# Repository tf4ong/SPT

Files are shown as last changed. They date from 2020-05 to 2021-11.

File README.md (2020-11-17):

# Home-cage Sucrose Preference Test
A scipt to run a chronic automated sucrose preference test of mice in home cage. The script is ran on a raspberry-pi with internet connection. A sucrose preference tunnel is attached to a rodent cage. The tunnel consists of a RFID reader for mouse identification, two double spouts for liquid dispension, capacitive touch sensor for lick detection, selenoids for reward delivery, IR light, and a fish-lens camera for behavior monitoring. An updated hardware list and setup instructions will be uploaded shortly. 
## MySql Database for Data Storage
- All behaviroal data (entries, exits, spout licked, type of reward dispensed) are logged on to the raspberry-pi MySql database. 
- The database is also hosted  by Apache HTTP Sever(version 2.4.43) and can be accessed through the internet
- Subsequent analytical scripts will also be uploaded
## RFID Identification
- A ID-20LA RFID tag reader will be at the beginning of the SPT tunnel to identify each mouse
## Spout choice At the of the Sucrose Preference Test Tunnel
- At the end of the tunnel there are two double spouts on each side
- The mouse and the spouts are spearted by a customed cut acrylic plastic (one hole corresponds to one double spout)
- A reward water/sucrose water is dispensed for every n links at each double spout. The n number of licks can be set accordingly
- Every 24 hour, the side which dispenses water/sucrose is swaped for the specific mouse
### Design and Layout of the Sucrose Preference Tunnel
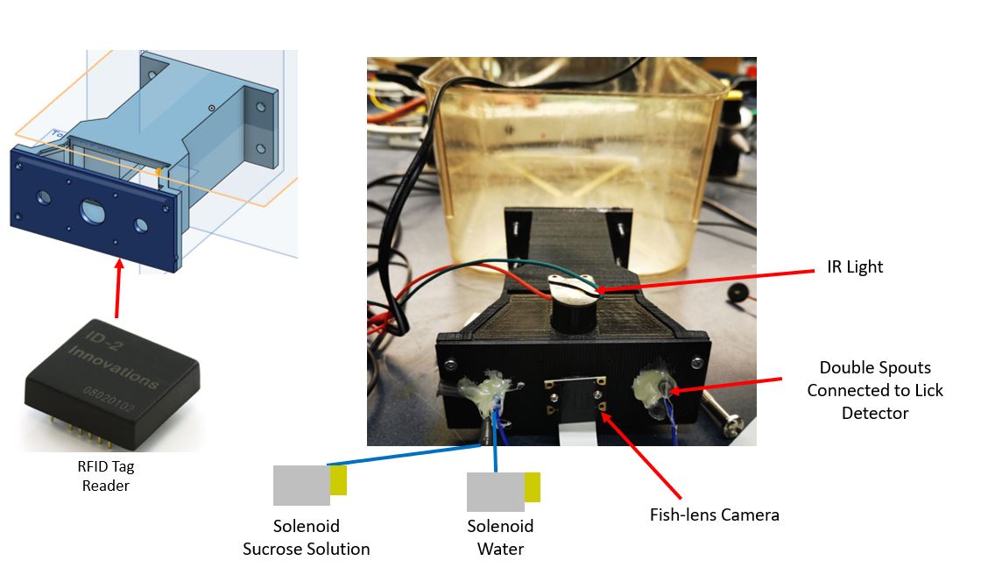
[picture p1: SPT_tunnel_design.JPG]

#### CAD Parts Assembly 
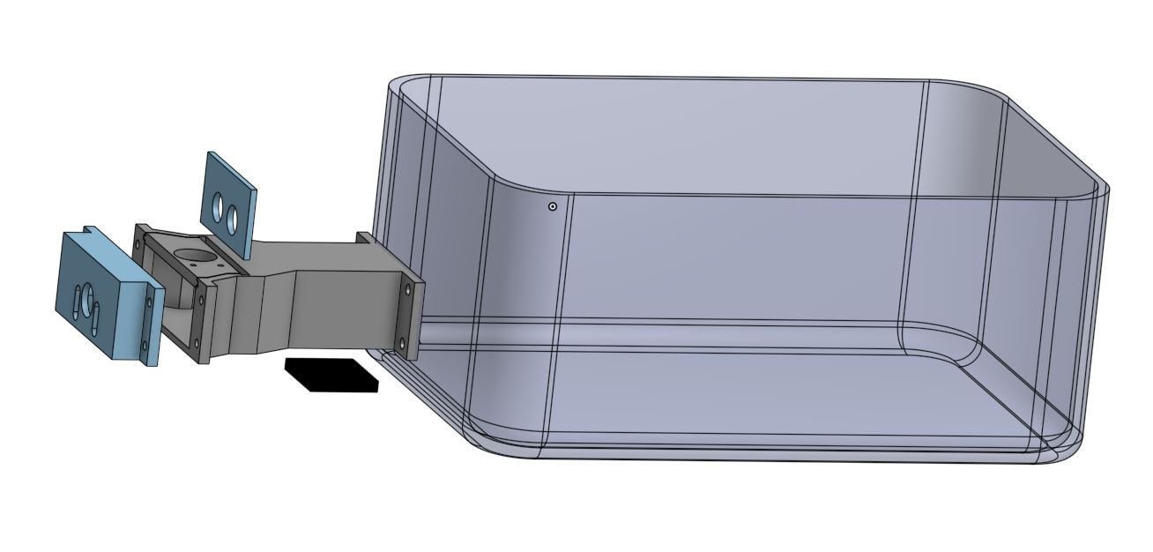
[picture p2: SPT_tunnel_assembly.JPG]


## Some Preliminary Videos
### Mouse Licking Spouts For Rewards In The Sucrose Preference Test Tunnel
Mouse Licking Right Spout             |  Mouse Licking Left Spout
:-------------------------:|:-------------------------:
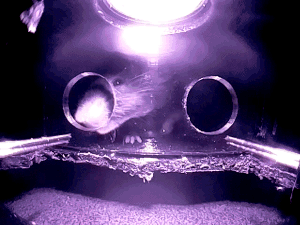
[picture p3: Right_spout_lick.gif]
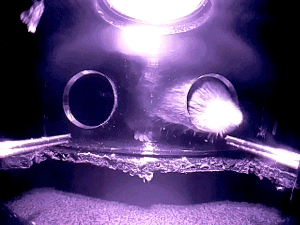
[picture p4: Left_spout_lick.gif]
 |

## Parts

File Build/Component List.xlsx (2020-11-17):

Component | Location | Price | Currency | Total Price in CAD | Notes | appendex | appendex | appendex
Raspberry Pi 3B + SD+power supply | https://www.buyapi.ca/product/raspberry-pi-3-model-b-plus/?src=raspberrypi | $67.85 | CAD | $67.85
Pi Cobbler | https://www.adafruit.com/product/2029 | $6.95 | USD | $8.69
Perma-Proto Board | https://www.adafruit.com/product/1606 | $6.95 | USD | $8.69
Bipolar (BJT) Transistor NPN | https://www.digikey.ca/en/products/detail/on-semiconductor/BC547BTA/1532789 | $0.30 | CAD | $1.20 | Four needed per cage
Solenoid Valve | http://canada.newark.com/gems-sensors/mb202-vb30-l203/solenoid-valve/dp/45M6131 | $99.47 | CAD | $397.88 | Four needed per cage; possible alternative (listed in appendex), price can be reduced from 397.88 to 95.94 ( including tubings) | https://www.amazon.ca/Pneumatic-Connector-Fittings-Industry-Automatic/dp/B07BLRG8SH | https://www.amazon.ca/URBEST-Meter-39-4ft-Pneumatic-Fittings/dp/B01M0DM5X5 | https://www.amazon.com/Normally-Pneumatic-Aluminum-Electric-Solenoid/dp/B07J4P99YZ
RFID USB Reader | https://www.sparkfun.com/products/9963 | $26.50 | USD | $33.12
RFID Reader ID20-LA | https://www.sparkfun.com/products/11828 | $34.95 | USD | $43.69
RFID Glass Capsules | https://www.sparkfun.com/products/9416 | $4.95 | USD | $6.19 | One is needed per animal to be tested (can be reused)
Mini-USB Cable | https://www.amazon.ca/AmazonBasics-USB-2-0-Cable-Male/dp/B00NH11N5A | $10.71 | CAD | $10.71
RPi Camera (G) | https://www.waveshare.com/product/rpi-camera-g.htm | $24.99 | USD | $31.24
18" Flex Cable | https://www.adafruit.com/product/1730 | $1.95 | USD | $2.44
TVS Diode | http://canada.newark.com/fairchild-semiconductor/p6ke36a/tvs-diode-600w-36v-do-15/dp/58K2101 | $0.22 | CAD | $0.88 | Four needed per cage
4.7kOhm Resistor | http://canada.newark.com/multicomp/mcre000041/carbon-film-resistor-axial-lead/dp/24R6895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 | $0.12 | CAD | $0.12
12V 1A Power Supply | https://www.adafruit.com/product/798 | $8.95 | USD | $11.19 | If building multiple cages, I recommend instead buying a 12V 5A charger, a four way splitter cable and extension cables (all available on adafruit)
Female DC Power to Screw Terminal | https://www.adafruit.com/product/368 | $2.00 | USD | $2.50
In-line Power Switch | https://www.adafruit.com/product/1125 | $2.50 | USD | $3.12
32 Oz Bottle w/Tubulation | https://www.usplastic.com/catalog/item.aspx?sku=68024&catid=1148 | $26.84 | USD | $67.10 | two bottles needed
1/8" Beverage Tubing | https://www.usplastic.com/catalog/item.aspx?sku=54413&catid=1065 | $5.83 | USD | $7.29 | Price is for a 25' roll (much less required for one cage)
1/4" Beverage Tubing | https://www.usplastic.com/catalog/item.aspx?itemid=85094 | $23.65 | USD | $29.56 | Price is for a 25' roll (much less required for one cage)
1/4" to 1/8" Coupler | https://www.usplastic.com/catalog/item.aspx?itemid=42622 | $0.59 | USD | $0.74
1/8" Luer | https://www.usplastic.com/catalog/item.aspx?itemid=118337 | $33.28 | USD | $41.60 | Price is for a pack of 100, but only two needed per system. Can be purchased in smaller packages on other websites (e.g. Sigma Aldrich).
3/16" Tubing Clamp | https://www.usplastic.com/catalog/item.aspx?sku=16004&catid=858 | $3.99 | USD | $4.99
18G Needle | https://www.mywellcare.ca/index.php?route=product/product&path=5&product_id=2778 | $22.00 | CAD | $22.00
3mm Acrylic Nose Poke Port |  | ???
Total Price: | $802.78

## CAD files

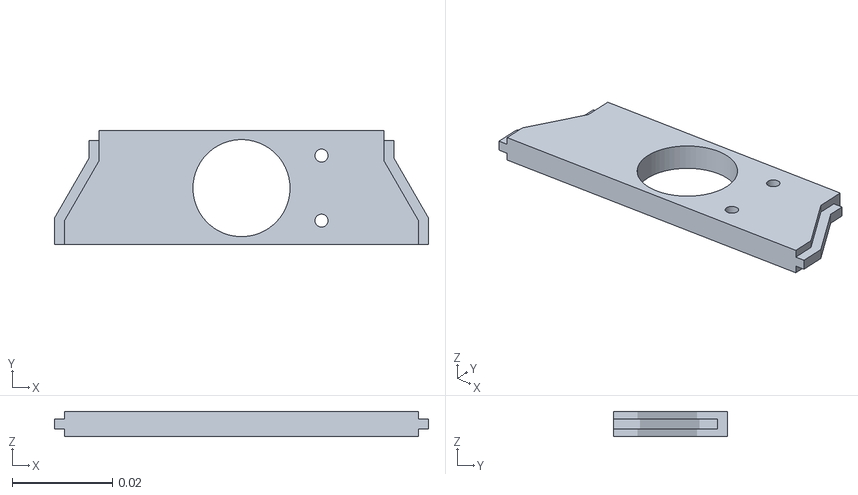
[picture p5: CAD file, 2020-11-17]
Build/CAD files/SPT chamber top.stl
0.0748 x 0.0227 x 0.005

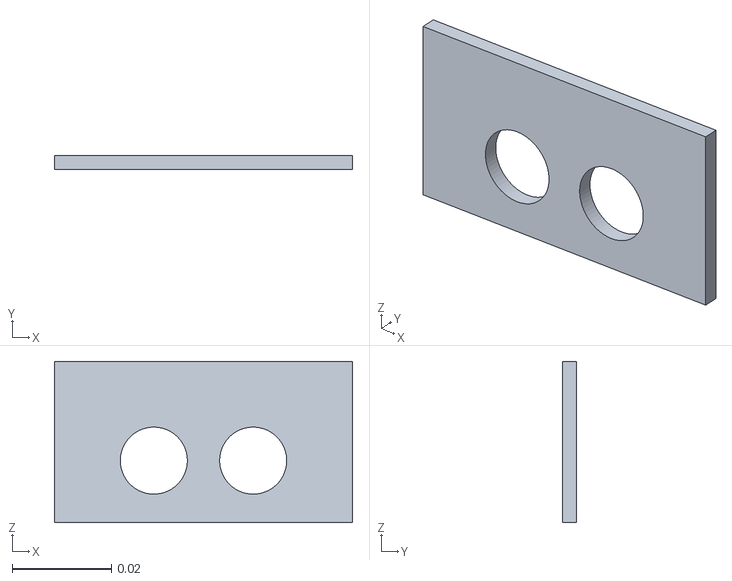
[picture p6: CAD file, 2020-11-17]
Build/CAD files/SPT slide glass.stl
0.06 x 0.0028 x 0.0325

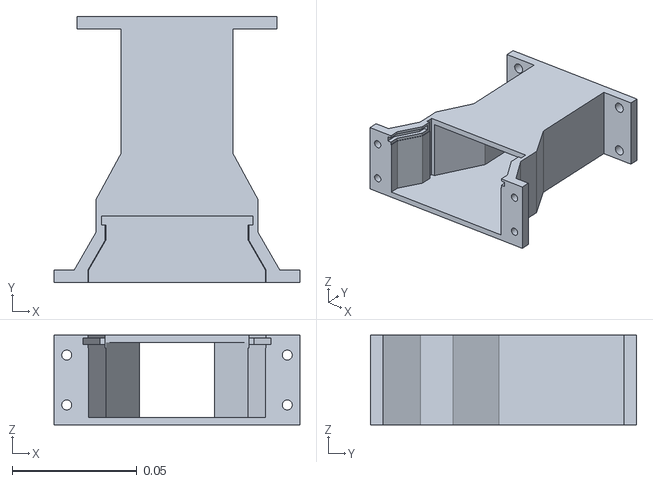
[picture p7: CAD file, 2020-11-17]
Build/CAD files/SPT chamber.stl
0.0983 x 0.106 x 0.036

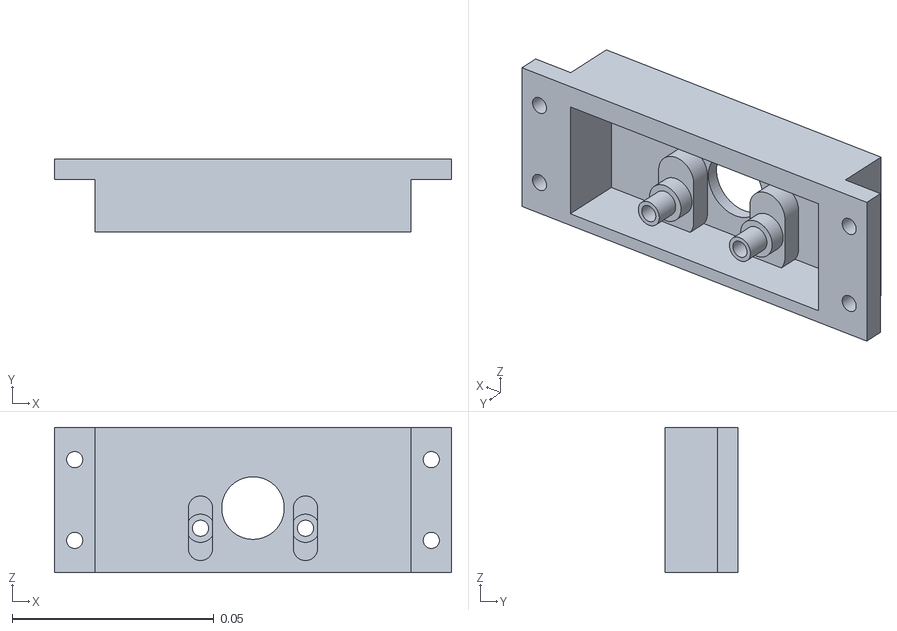
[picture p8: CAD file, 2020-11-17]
Build/CAD files/SPT chamber front.stl
0.0983 x 0.018 x 0.036

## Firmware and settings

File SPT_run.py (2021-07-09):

from time import time, sleep
import board
import busio
import numpy as np
from SPT import SPT 
import RFIDTagReader
from RFIDTagReader import TagReader
import RPi.GPIO as GPIO 
import datetime as dt
import adafruit_mpr121 as mpr121
import sys
import os
from _thread import start_new_thread
import argparse
import socket 
ip="10.21.229.93"
port= 2555
'''
Hardware variables to be read by json file
'''

def load_settings(task_name):
    task_settings=SPT.task_settings(task_name)
    try:
        task_settings.task_config
    except AttributeError:
        print('Creating new task settings file')
        task_settings.write_new_settings()
    else: 
        pass
    return  task_settings
def entrance_reward(t):
    try:
        if mice_dic.mice_config[str(t)]['SPT_level']== 0:
            #probability=np.random.choice([0,1],p=[0.5,0.5])
            #if int(probability)==1:
            selenoid_LW.activate(0.07)
            selenoid_RW.activate(0.07)
            log.event_outcome(mice_dic.mice_config,str(t),'Entered','Entry_Reward_RL')
            #elif int(probability)==0:
            #    selenoid_RW.activate(0.106)
            #    log.event_outcome(mice_dic.mice_config,str(t),'Entered','Entry_Reward_R')
            #    pass
        elif mice_dic.mice_config[str(t)]['SPT_level']== 1:
            if mice_dic.mice_config[str(t)]['SPT_Pattern']=='R':
                selenoid_RW.activate(0.07)
                log.event_outcome(mice_dic.mice_config,str(t),'Entered','Entry_Reward_R')
            elif mice_dic.mice_config[str(t)]['SPT_Pattern']=='L':
                selenoid_LW.activate(0.07)
                log.event_outcome(mice_dic.mice_config,str(t),'Entered','Entry_Reward_L')
        else:
            log.event_outcome(mice_dic.mice_config,str(t),'Entered','No_Entry_Reward')
    except Exception as e:
        print(e)
        print('new_tag, need to log the mice')
        #log.event_outcome(mice_dic.mice_config,str(tag),'New_mice','None')

def rewarder_R(tt):
    try:
        if mice_dic.mice_config[str(tt)]['SPT_level'] ==0:
            selenoid_RW.activate(0.07)
            log.event_outcome(mice_dic.mice_config,str(tt),'licked-Rightside','Water_Reward')
        elif mice_dic.mice_config[str(tt)]['SPT_level'] ==1:
            if mice_dic.mice_config[str(tt)]['SPT_Pattern']=='R':
                selenoid_RW.activate(0.07)
                log.event_outcome(mice_dic.mice_config,str(tt),'licked-Rightside','Water_Reward')
            elif mice_dic.mice_config[str(tt)]['SPT_Pattern']=='L':
                #speaker on 
                #print('Speaker on\n')
                #buzzer.buzz()
                log.event_outcome(mice_dic.mice_config,str(tt),'licked-Rightside','No_Reward')
        elif mice_dic.mice_config[str(tt)]['SPT_level'] ==2:
            if mice_dic.mice_config[str(tt)]['SPT_Pattern']=='R':
                selenoid_RS.activate(0.07)
                log.event_outcome(mice_dic.mice_config,str(tt),'licked-Rightside','Sucrose_Reward')
            elif mice_dic.mice_config[str(tt)]['SPT_Pattern']=='L':
                selenoid_RW.activate(0.07)
                log.event_outcome(mice_dic.mice_config,str(tt),'licked-Rightside','Water_Reward')
    except Exception as e:
        print(e)
        print('new_tag, need to log the mice')
        #log.event_outcome(mice_dic.mice_config,str(tag),'New_mice','None')
        pass
def rewarder_L(tt):
    try:
        if mice_dic.mice_config[str(tt)]['SPT_level'] ==0:
            selenoid_LW.activate(0.07)
            log.event_outcome(mice_dic.mice_config,str(tt),'licked-Lefttside','Water_Reward')
        elif mice_dic.mice_config[str(tt)]['SPT_level'] ==1:
            if mice_dic.mice_config[str(tt)]['SPT_Pattern']=='L':
                selenoid_LW.activate(0.07)
                log.event_outcome(mice_dic.mice_config,str(tt),'licked-Leftside','Water_Reward')
            elif mice_dic.mice_config[str(tt)]['SPT_Pattern']=='R':
                #speaker on 
                #print('Speaker on\n')
                #buzzer.buzz()
                log.event_outcome(mice_dic.mice_config,str(tt),'licked-Leftside','No_Reward')
        elif mice_dic.mice_config[str(tt)]['SPT_level'] ==2:
            if mice_dic.mice_config[str(tt)]['SPT_Pattern']=='L':
                selenoid_LS.activate(0.07)
                log.event_outcome(mice_dic.mice_config,str(tt),'licked-Leftside','Sucrose_Reward')
            elif mice_dic.mice_config[str(tt)]['SPT_Pattern']=='R':
                selenoid_LW.activate(0.07)
                log.event_outcome(mice_dic.mice_config,str(tt),'licked-Leftside','Water_Reward')
    except Exception as e:
        print(e)
        print('new_tag, need to log the mice')
        #log.event_outcome(mice_dic.mice_config,str(tag),'New_mice','None')
        pass
"""
Main loop for SPT 
"""
#Start of main function to run SPT
def main():
    global globalReader
    global globalTag
    global cage
    global log
    global GPIO
    global mice_dic 
    global now
    filename='None'
    try:
        sock= socket.socket(socket.AF_INET, socket.SOCK_DGRAM)
    except Exception as e:
        print(e)
        print("Unable to connect")
    send_RFID=False
    globalReader = TagReader(serialPort, True, timeOutSecs = 0.05, kind='ID')
    globalReader.installCallback (tag_in_range_pin)
    #Starting loop to check time passed
    #After n hours (in json file), the SPT spouts are switched from each sides
    #reads the mouse dict file
    mice_dic=SPT.mice_dict(cage)
    #the text spacer: comma for csv
    txtspacer=','
    #loop to check time
    #initiating counter to check days
    count=0
    while True:
        count+=1
        if type(now) == str:
            if now == 'none':
                now=dt.datetime.now()
            else:
                now= dt.datetime.strptime(now,'%Y-%m-%d_%H-%M-%S')
        else:
            now=dt.datetime.now() 
        current_touched = cap.touched()
        print ("Waiting for mouse....")
        #starts new text file and switches spouts if not on day 1
        log=SPT.data_logger(cage,txtspacer)
        #changes the spouts if day counter is not one 
        if count != 1:
            mice_dic.spout_swtich()
            print('Spout Switched')
        else:
            pass
        #if within same day, the main loop is ran
        while dt.datetime.now()-now < dt.timedelta(minutes=hours*60):
            #Waiting for a tag to be read
            if RFIDTagReader.globalTag == 0:
                #try:
                    #vs.stop_record()
                    #log.event_outcome(mice_dic.mice_config,str(tag),'CameraStopped',filename)
                #    print('camera stopped1')
                #except Exception:
                #    pass
                sleep (0.2)
            else:
                tag_movement_time=time()
                if RFIDTagReader.globalTag != 0 or time()-tag_movement_time<1:  
                 #tag just been read, starting video and logging events 
                    tag = RFIDTagReader.globalTag
                    #import pdb; pdb.set_trace()
                    #filename=vs.record(tag)
                    log.event_outcome(mice_dic.mice_config,str(tag),'VideoStart',filename)
                    #if at SPT level 0, an entry reward is given, if not pass 
                    entrance_reward(tag)
                    message_to_send='i'+str(tag)
                    sock.sendto(message_to_send.encode("utf-8"),(ip,port))
                    lick_count_R=0
                    lick_count_L=0
                    #loop for tag read and in range
                    while RFIDTagReader.globalTag == tag or time()-tag_movement_time<1:
                        last_touched = cap.touched()
                        while GPIO.input(tag_in_range_pin) == GPIO.HIGH:
                            #creates a temporary tag for reference, temp tag is recorded if not tag is not zero,globaltag is reset to 0 each time
                            if tag !=0:
                                temp_tag=tag
                            else:
                                pass
                     #the spt task at three different levels 
                            for i in range(8):
                                current_touched = cap.touched()
                                pin_bit = 1 << i
                                if current_touched & pin_bit and not last_touched & pin_bit:
                                    if i==2:
                                        lick_count_R+=1
                                        message_to_send='l'+str(temp_tag)
                                        sock.sendto(message_to_send.encode("utf-8"),(ip,port))
                                        if lick_count_R%2 == 0:
                                            rewarder_R(temp_tag)
                                        else:
                                            log.event_outcome(mice_dic.mice_config,str(temp_tag),'licked-Rightside','No_Reward')
                                    elif i==0:
                                        lick_count_L+=1
                                        message_to_send='l'+str(temp_tag)
                                        sock.sendto(message_to_send.encode("utf-8"),(ip,port))
                                        if lick_count_L%2 == 0:
                                            #pass
                                            rewarder_L(temp_tag)
                                        else:
                                            log.event_outcome(mice_dic.mice_config,str(temp_tag),'licked-Leftside','No_Reward')
                                    else:
                                        pass
                            last_touched = current_touched
                            sleep(0.05)
                        # tag just went out of range, loop for grace period
                        if GPIO.input(tag_in_range_pin) == GPIO.LOW: 
                        #starts the grace timer, within the grace period the task still continues and waits for the tag to return
                            grace_start=time()
                            message_to_send='o'+str(temp_tag)
                            sock.sendto(message_to_send.encode("utf-8"),(ip,port))
                            print('GracePeriod Starts')
                            while GPIO.input(tag_in_range_pin) == GPIO.LOW and time()-grace_start<gracePeriod:
                                #last_touched = cap.touched()
                         #the spt task at three different levels 
                                for i in range(2):
                                    current_touched = cap.touched()
                                    pin_bit = 1 << i
                                    if current_touched & pin_bit and not last_touched & pin_bit:
                                        if i==2:
                                            lick_count_R+=1
                                            message_to_send='l'+str(temp_tag)
                                            sock.sendto(message_to_send.encode("utf-8"),(ip,port))
                                            if lick_count_R%2 == 0:
                                                rewarder_R(temp_tag)
                                            else:
                                                log.event_outcome(mice_dic.mice_config,str(temp_tag),'licked-Rightside','No_Reward')
                                        elif i==0:
                                            lick_count_L+=1
                                            message_to_send='l'+str(temp_tag)
                                            sock.sendto(message_to_send.encode("utf-8"),(ip,port))
                                            if lick_count_L % 2 == 0:
                                                #pass
                                                rewarder_L(temp_tag)
                                            else:
                                                log.event_outcome(mice_dic.mice_config,str(temp_tag),'licked-Leftside','No_Reward')
                                    else:
                                        pass
                                last_touched = current_touched
                                sleep(0.05)
                           #When tag returns (tag read is the same as temp tag), assigns the gloablTag to temp the tag read and returns to the previous loop
                                tag = RFIDTagReader.globalTag
                                if tag == temp_tag:
                                    RFIDTagReader.globalTag=temp_tag
                                    message_to_send='i'+str(temp_tag)+'ipo'
                                    sock.sendto(message_to_send.encode("utf-8"),(ip,port))
                                else:
                                    if tag != 0:
                                        log.event_outcome(mice_dic.mice_config,str(temp_tag),'Exit','None')
                                        message_to_send='o'+str(temp_tag)+'c'
                                        sock.sendto(message_to_send.encode("utf-8"),(ip,port))
                                        temp_tag=tag
                                        log.event_outcome(mice_dic.mice_config,str(temp_tag),'Entered','None')
                                        RFIDTagReader.globalTag=temp_tag
                                        message_to_send='i'+str(temp_tag)
                                        sock.sendto(message_to_send.encode("utf-8"),(ip,port))
                                        break
                                    else:
                                        pass
                           #add loop/condition to break if new tag != temp tag; breaks out of loop and stop video recording and assigns new mice entry and video start
                           #if the time passes the grace period,stops recording and logs events then breaks out of the loop to get back the previous loop
                            if GPIO.input(tag_in_range_pin) == GPIO.LOW and time()-grace_start>=gracePeriod:   
                                print('grace period expired')
                                #vs.stop_record()
                                log.event_outcome(mice_dic.mice_config,str(temp_tag),'VideoEnd',filename)
                                sleep(0.05)
                                log.event_outcome(mice_dic.mice_config,str(temp_tag),'Exit','None')
                                message_to_send='o'+str(temp_tag)+'cg'
                                sock.sendto(message_to_send.encode("utf-8"),(ip,port))
                                print('Waiting for mouse')
                                #break to get back in loop 2 
                                #continue
                                break
                else:
                    #vs.stop_record()
                    log.event_outcome(mice_dic.mice_config,str(tag),'Mous_not_stable',filename)

#Running the script with some settings read from json file
if __name__ == '__main__':
    parser=argparse.ArgumentParser()
    parser.add_argument('-task',metavar='task_name',type=str,help='Task settings to run SPT',default='none')
    parser.add_argument('-cage',metavar='cage',type=str,help='Cage to run SPT',default='none')
    parser.add_argument('-time',metavar='now',type=str,help='Time of day before last shut down',default='none')
    args=parser.parse_args()
    if args.task is 'none':
        task_name=input('Enter the task name: ')
    else:
        task_name=args.task
    if args.cage is 'none':
        cage=input('Enter the cage to run: ')
    else:
        cage=args.cage
    now=args.time
    task_settings=load_settings(task_name)
    print(task_settings.task_config)
    #mice interference
    gracePeriod=3
    try: 
        tag_in_range_pin=task_settings.task_config['tag_in_range_pin']
        selenoid_pin_LW=task_settings.task_config['selenoid_pin_LW']
        selenoid_pin_LS=task_settings.task_config['selenoid_pin_LS']
        selenoid_pin_RW=task_settings.task_config['selenoid_pin_RW']
        selenoid_pin_RS=task_settings.task_config['selenoid_pin_RS']
        buzzer_pin=task_settings.task_config['buzzer_pin']
        vid_folder=task_settings.task_config['vid_folder']
        hours=task_settings.task_config['hours']
        serialPort = '/dev/ttyUSB0'
        i2c=busio.I2C(board.SCL,board.SDA)
        cap = mpr121.MPR121(i2c,address=0x5A)
        selenoid_RW=SPT.selenoid(selenoid_pin_RW)
        selenoid_RS=SPT.selenoid(selenoid_pin_RS)
        selenoid_LW=SPT.selenoid(selenoid_pin_LW)
        selenoid_LS=SPT.selenoid(selenoid_pin_LS)
        globalReader = None
        globalTag = 0
        #vs=SPT.piVideoStream(folder=vid_folder)
        #vs.cam_setup()
        buzzer=SPT.buzzer(buzzer_pin,1500,50)
    except Exception as e: 
        print(e)
        print('Error in iniatializing hardware, please check wiring and task settings')
        print('System shuting down')
        sys.exit()
    if not os.path.exists(cage+'/'):
        os.mkdir(cage+'/')
        print(cage+' Dictionary created')
    mice_dic=SPT.mice_dict(cage)      
    while True:
        try:
            if not os.path.exists(cage+'/'):
                os.mkdir(cage+'/')
                print(cage+' Dictionary created')
            mice_dic=SPT.mice_dict(cage)
            try: 
                main()
            #the SPT option manual for SPT, currently just a template
            except KeyboardInterrupt:
                #print('1')
                inputStr = '\n************** SPT Manager ********************\nEnter:\n'
                inputStr += '1 to change SPT level for mice\n'
                inputStr += '2 to change SPT task settings\n'
                inputStr += '3 to add mice\n'
                inputStr += '4 to remove mice\n'
                inputStr += 'R to Return to head fix trials\n'
                inputStr += 'Q to quit\n:'
                event = input(inputStr)
                if event == 'r' or event == "R":
                    pass
                elif event == 'q' or event == 'Q':
                    sys.exit()
        except Exception as anError:
            print('SPT error:' + str(anError))
            raise anError
        finally:
            print('Quitting SPT run')
            #with open ('starttime_log.txt','w') as file:
            #    file.write(cage+'\n')
            #    file.write(now.strftime('%Y-%m-%d_%H-%M-%S'))
            print(now)
            print('Restarting SPT')
            mice_dic=SPT.mice_dict(cage)
            #GPIO.cleanup()
            #sys.exit()

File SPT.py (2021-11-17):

import RPi.GPIO as GPIO
from time import sleep
import time
import board
import busio
import datetime as dt
from picamera import PiCamera
from threading import Thread
import cv2
from picamera import PiCamera
import os
import json
import pymysql
class selenoid:
	def __init__(self, pin):
		GPIO.setmode(GPIO.BCM)
		self.pin=pin
		GPIO.setup(self.pin,GPIO.OUT)
	def activate(self,open_time):
		GPIO.setwarnings(False)
		GPIO.output(self.pin,GPIO.HIGH)
		sleep(float(open_time))
		GPIO.output(self.pin,GPIO.LOW)
	def flush(self):
		GPIO.setwarnings(False)
		GPIO.output(self.pin,GPIO.HIGH)
	def close(self):
		GPIO.setwarnings(False)
		GPIO.output(self.pin,GPIO.LOW)
class data_logger:
	def __init__(self,cage,txtspacer):
		self.cage=cage
		self.txtspacer=txtspacer
		today=dt.datetime.now().strftime('%Y-%m-%d-%H-%M-%S')
		self.filename=self.cage+'/'+'SPT_'+today+'_'+self.cage+'.csv'
		try:
			con=pymysql.connect(host='localhost',user='pi',db='SPT_raw_data',password='SPT2019',autocommit=True)
			cur1=con.cursor()
			insert_statment='INSERT INTO SPT_raw_data (Timestamp,Tag,SPT_level,SPT_pattern,Event,Event_dict,Cage) VALUES (%s,%s,%s,%s,%s,%s,%s)'
		except Exception as e:
			print(e)
			print('Not able to connect to local db, check connections or creditials')
			pass
		if not os.path.exists(cage+'/'):
			os.mkdir(self.cage+'/')
			print(cage+' Dictionary created')
		else:
			pass
		if not os.path.exists(self.filename):
			print(dt.datetime.now().strftime('%Y-%m-%d %H-%M-%S.%f')[:-3]+' Starting a new day starting SPT')
			with open(self.filename,'a') as file:
				file.write('Time,Tag,Surcose_Pattern,SPT_level,Event,Event_dict\n')
		else:
			pass
		self.con=con
		self.cursor=cur1
		self.insert_statment=insert_statment
		values=[dt.datetime.now().strftime('%Y-%m-%d %H-%M-%S'),'Newday','Newday','Newday','Newday','Newday',self.cage]
		self.cursor.execute(self.insert_statment,values)
	def event_outcome(self,mice,mouse,event,event_dict):
		spacer="    "
		try:
		    sucrose_pattern=mice[mouse]['SPT_Pattern']
		    spt_level=str(mice[mouse]['SPT_level'])
		    current_time=dt.datetime.now().strftime('%Y-%m-%d %H-%M-%S.%f')[:-3]
		    Event= current_time+spacer+mouse+spacer+sucrose_pattern+spacer+spt_level+spacer+event+spacer+event_dict
		    with open(self.filename,'a') as file:
			    file.write(dt.datetime.now().strftime('%Y-%m-%d %H-%M-%S')+self.txtspacer+mouse+self.txtspacer+sucrose_pattern+self.txtspacer+spt_level+self.txtspacer+event+self.txtspacer+event_dict+'\n')
		    values=[dt.datetime.now().strftime('%Y-%m-%d %H-%M-%S'),str(mouse),str(spt_level),sucrose_pattern,event,event_dict,self.cage]
		    self.cursor.execute(self.insert_statment,values)
		    print(Event+'\n')
		except Exception:
			pass
class piVideoStream:
	def __init__(self,folder,resolution=(640,480),framerate=90,vidformat='h264',quality=25,preview=(0,0,640,480)):
		self.cam=PiCamera()
		self.resolution=resolution
		self.framerate=framerate
		self.vidformat=vidformat
		self.quality=quality
		self.preview=preview
		self.folder= folder
	def cam_setup(self):
		self.cam.resolution=self.resolution
		self.cam.framerate=self.framerate 
	def record(self,tag):
		self.cam.start_preview(fullscreen=False,window=self.preview)
		self.filename=str(tag)+'_'+dt.datetime.now().strftime('%Y-%m-%d-%H-%M-%S')+'.h264' 
		self.filepath=self.folder+self.filename
		self.cam.start_recording(self.filepath,quality=self.quality)
		return self.filename
	def stop_record(self):
		self.cam.stop_preview()
		self.cam.stop_recording()
		self.cam.close()
class buzzer:
	def __init__(self,pin,pitch,times):
		GPIO.setmode(GPIO.BCM)
		self.pin=pin
		self.delay=(1/pitch)/2
		self.cycle=times
		GPIO.setup(self.pin,GPIO.OUT)
	def buzz(self):
		for i in range(self.cycle):
			GPIO.output(self.pin, True)
			sleep(self.delay)
			GPIO.output(self.pin, False)
			sleep(self.delay)
'''
need to integrate into main as class
'''
import json
import datetime as dt
from RFIDTagReader import TagReader
RFID_serialPort = '/dev/ttyUSB0'
RFID_kind = 'ID'
RFID_timeout = None
RFID_doCheckSum = True
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

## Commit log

2020-02-26 Update test.py
    Got rid of spout switching for the first day of test/protocol
2021-11-17 updated camera function
